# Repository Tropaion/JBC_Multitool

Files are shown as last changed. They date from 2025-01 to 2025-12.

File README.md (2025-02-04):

# JBC_Multitool
A slot extension device for JBC soldering stations with only one soldering iron terminal.
It is possible to connect:

* 2x soldering iron with the old hirose connector, like the [T210](https://www.weidinger.eu/de/wl13282) and [T245](https://www.weidinger.eu/de/wl13283)
* 2x soldering iron with the newer binder connector, like the [NT115A](https://www.weidinger.eu/de/wl44430) and [AN115A](https://www.weidinger.eu/de/wl45372)

THE PROJECT IS STILL WIP.

# Hardware
View the latest [PCB Interactive BOM](https://htmlpreview.github.io/?https://github.com/Tropaion/JBC_Multitool/blob/main/hardware/bom/ibom.html) or [KiCad Design](https://kicanvas.org/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).

<p float="left">
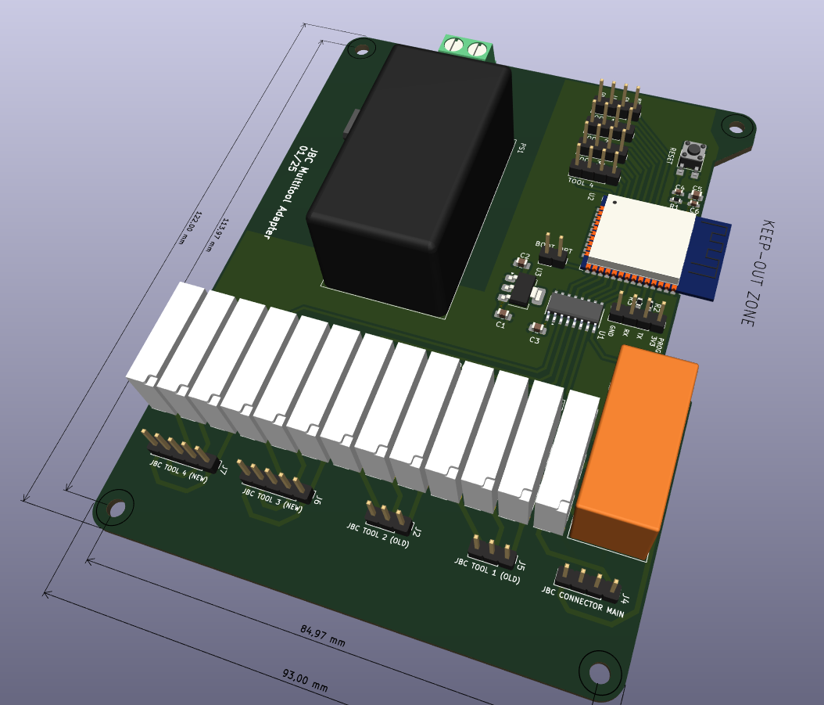
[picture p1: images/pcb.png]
  
</p>

# Attribution
This project is based on [this project from Lajt](https://lajtronix.eu/2024/02/08/jbc-3-tool-selector/)

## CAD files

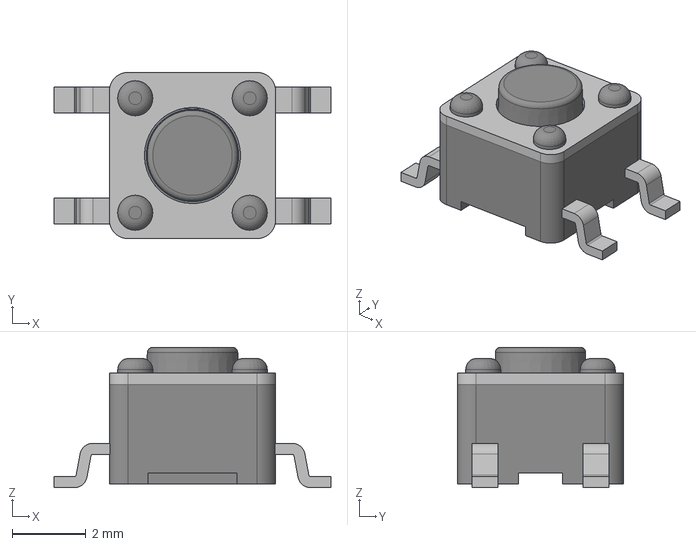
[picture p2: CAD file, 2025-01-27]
hardware/custom_components/3d/SW_SPST_TL3305A.step
7.50 x 4.50 x 3.80 mm

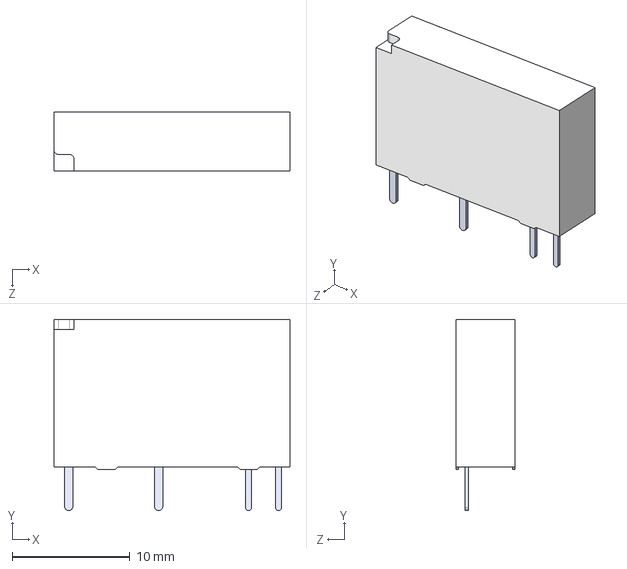
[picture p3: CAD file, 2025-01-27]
hardware/custom_components/3d/HF49FD.step
20.0 x 16.2 x 5.00 mm

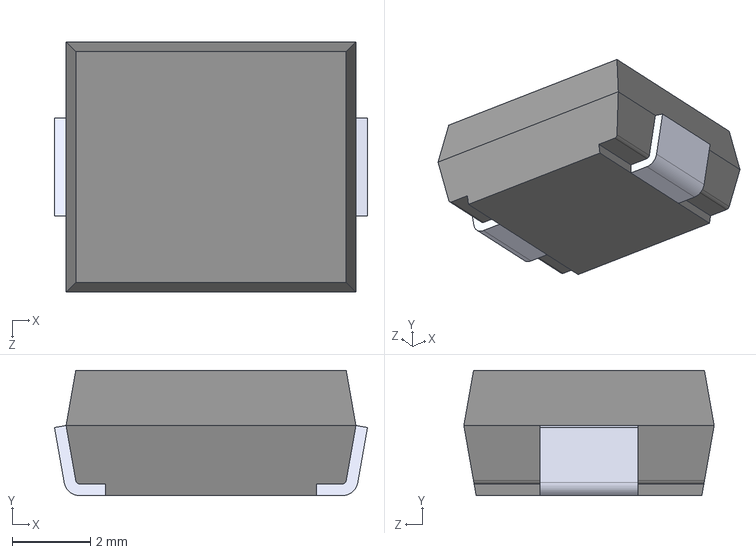
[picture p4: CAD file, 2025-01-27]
hardware/custom_components/3d/ERZ-VF2M470.step
8.00 x 3.20 x 6.40 mm

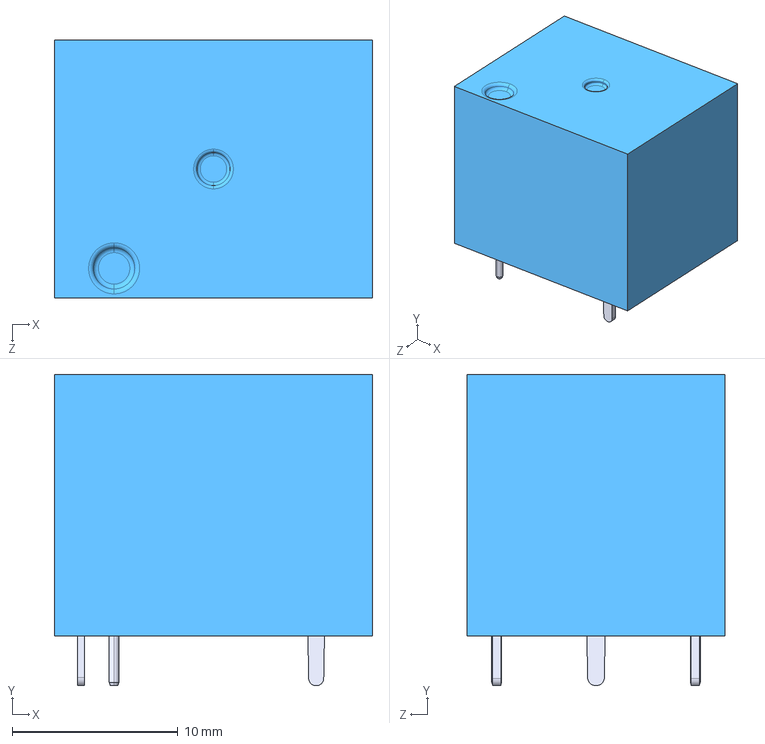
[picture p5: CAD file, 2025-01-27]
hardware/custom_components/3d/SRD-05VDC-SL-C.step
19.2 x 18.8 x 15.6 mm

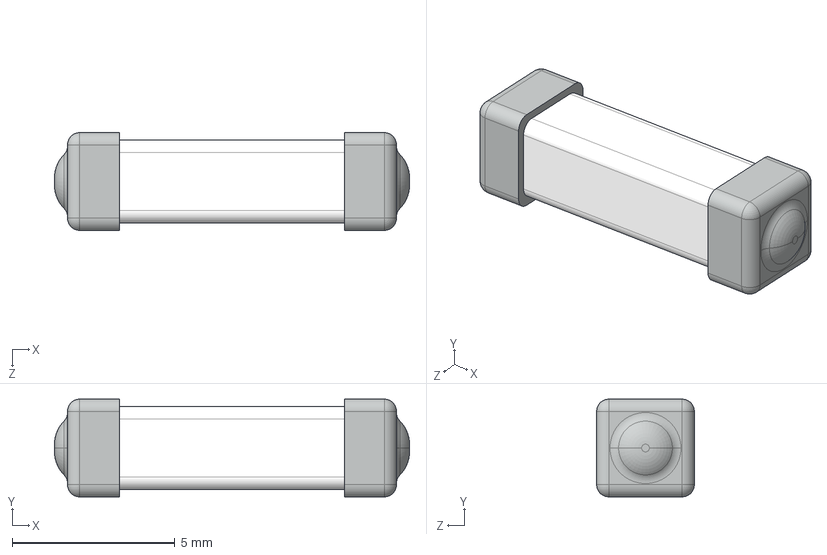
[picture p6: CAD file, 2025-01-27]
hardware/custom_components/3d/UMT250.step
10.9 x 3.00 x 3.00 mm

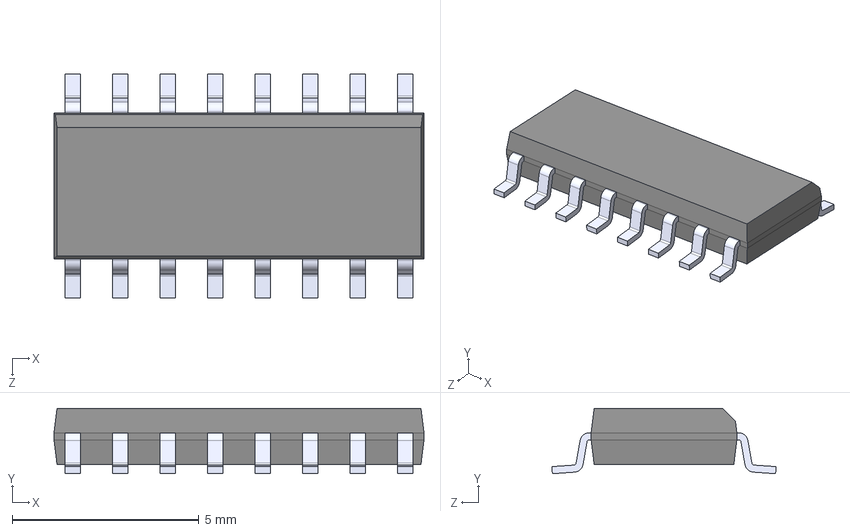
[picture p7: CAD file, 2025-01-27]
hardware/custom_components/3d/TPL7407LDR.step
9.90 x 1.75 x 6.00 mm

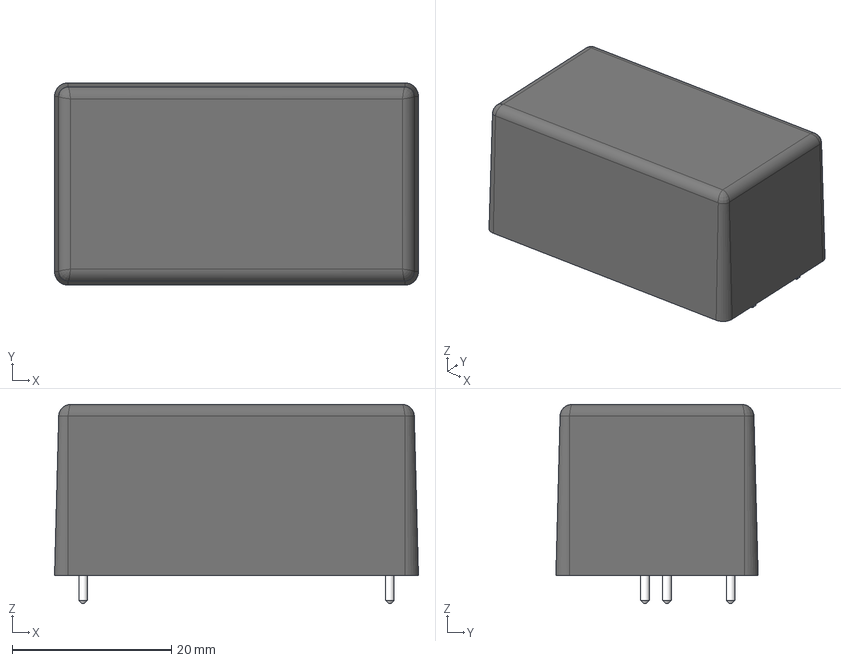
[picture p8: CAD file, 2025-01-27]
hardware/custom_components/3d/IRM-10 v3.step
45.7 x 25.4 x 25.0 mm

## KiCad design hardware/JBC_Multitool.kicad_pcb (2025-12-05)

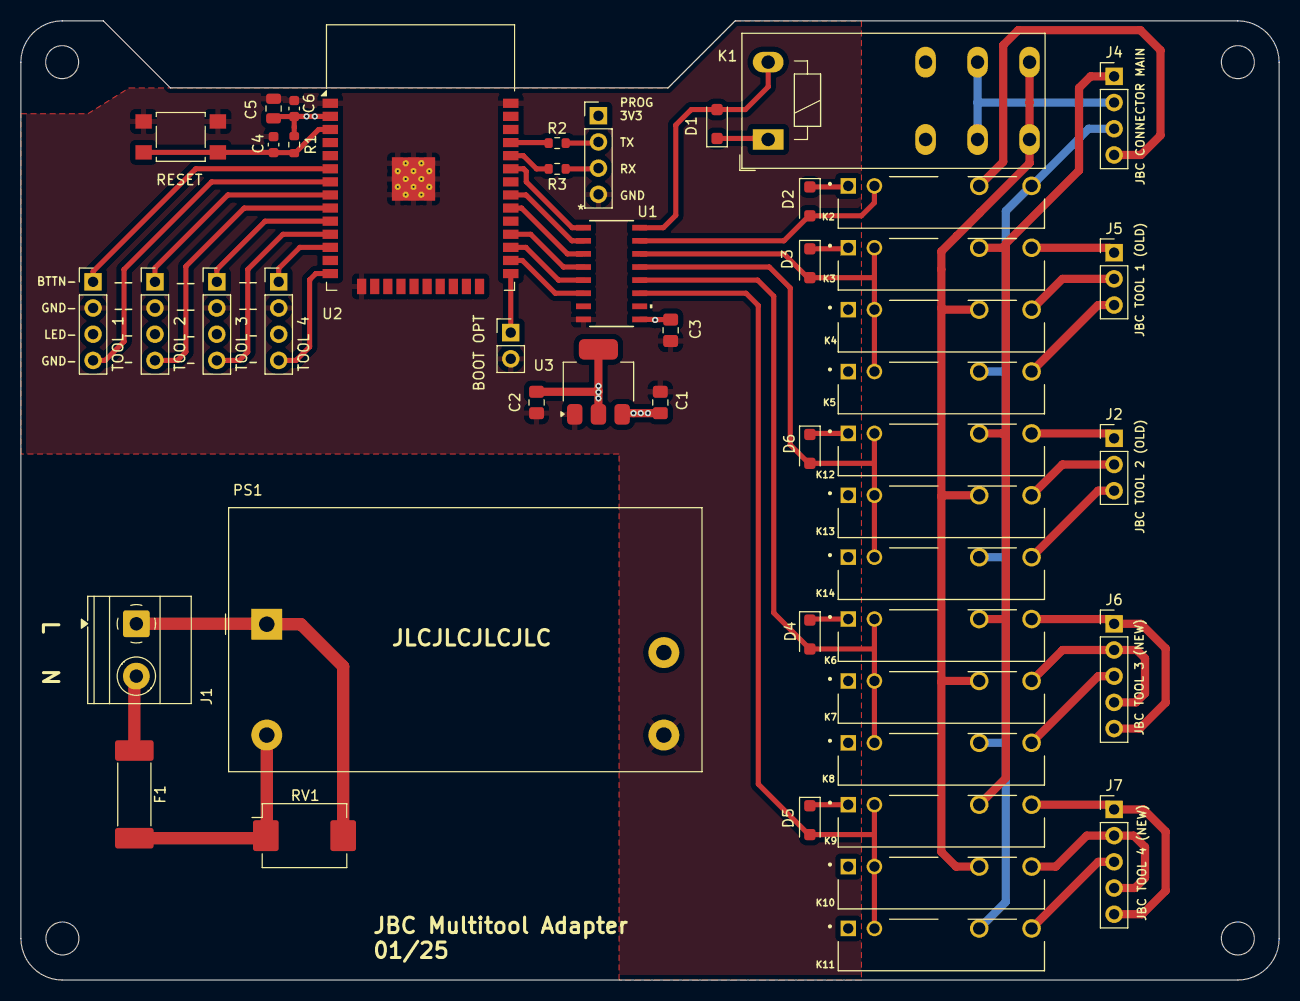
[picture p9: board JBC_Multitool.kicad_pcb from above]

Board: 2 copper layers, 122.0 x 93.0 mm, 52 parts (0 on the bottom side), 45 nets.

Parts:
BOOT_OPTION1: Conn_01x02; PinHeader_1x02_P2.54mm_Vertical
C1, C2: 1uF/10V; C_0805_2012Metric_Pad1.18x1.45mm_HandSolder
C3: 0.1uF; C_0805_2012Metric_Pad1.18x1.45mm_HandSolder
C4: 1µF/16V/10%; C_0603_1608Metric
C5: 22µF/10V; C_0805_2012Metric
C6: 0.1µF/50V/10%; C_0603_1608Metric
D1, D2, D3, D4, D5, D6: D; D_SOD-123F
ESP_RESET1: SW_Push; SW_SPST_TL3305A
F1: 100mA T; Fuse_Schurter_UMT250
H1, H2, H3, H4: MountingHole; MountingHole_3.2mm_M3
J1: Screw_Terminal_01x02; TerminalBlock_Phoenix_MKDS-1,5-2-5.08_1x02_P5.08mm_Horizont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
J2, J5: Mini XLR6; PinHeader_1x03_P2.54mm_Vertical
J4: Mini XLR6; PinHeader_1x04_P2.54mm_Vertical
J6, J7: Binder 09-0998-00-05; PinHeader_1x05_P2.54mm_Vertical
K1: RT314005; Relay_DPDT_Schrack-RT2-FormC_RM5mm
K2, K3, K4, K5, K6, K7, K8, K9, K10, K11, K12, K13, K14: HF49FD_005-1H12T; HF49FD
PROG1: Conn_01x04; PinHeader_1x04_P2.54mm_Vertical
PS1: IRM-10-5; Converter_ACDC_MeanWell_IRM-10-xx_THT
R1: 10kΩ 1%; R_0603_1608Metric
R2, R3: 160Ω; R_0603_1608Metric
RV1: Varistor 230V; Varistor_Panasonic_VF
SELECT_TOOL_1, SELECT_TOOL_2, SELECT_TOOL_3, SELECT_TOOL_4: Conn_01x04; PinHeader_1x04_P2.54mm_Vertical
U1: TPL7407LDR; D16_TEX
U2: ESP32-WROOM-32
U3: TLV1117-33; SOT-223-3_TabPin2

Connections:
+3.3V: C2.1, C5.2, C6.2, PROG1.1, R1.2, SELECT_TOOL_1.3, SELECT_TOOL_2.3, SELECT_TOOL_3.3, SELECT_TOOL_4.3, U2.2 (VDD), U3.2 (VO)
+5V: C1.1, C3.1, D1.1 (K), D2.1 (K), D3.1 (K), D4.1 (K), D5.1 (K), D6.1 (K), K1.A1, K2.1, K3.1, K4.1, K5.1, K6.1, K7.1, K8.1, K9.1, K10.1, K11.1, K12.1, K13.1, K14.1, PS1.4 (+Vo), U1.9 (COM), U3.3 (VI)
/ESP_RESET: C4.2, ESP_RESET1.2, R1.1, U2.3 (EN)
/GPIO0_BOOT_OPTION: BOOT_OPTION1.1, U2.25 (IO0)
/RELAIS_CARD/TOOL_1_SEL: D3.2 (A), K3.2, K4.2, K5.2, U1.14 (OUT3)
/RELAIS_CARD/TOOL_2_SEL: D6.2 (A), K12.2, K13.2, K14.2, U1.13 (OUT4)
/RELAIS_CARD/TOOL_3_SEL: D4.2 (A), K6.2, K7.2, K8.2, U1.12 (OUT5)
/RELAIS_CARD/TOOL_4_SEL: D5.2 (A), K9.2, K10.2, K11.2, U1.11 (OUT6)
/RELAIS_CARD/TOOL_CODE: K2.4, K5.3, K8.3, K11.3, K14.3
/RELAIS_CARD/TOOL_CODE_SEL: D2.2 (A), K2.2, U1.15 (OUT2)
/RELAIS_CARD/TOOL_POWER: K4.3, K7.3, K10.3, K13.3
/RELAIS_CARD/TOOL_POWER_SEL: D1.2 (A), K1.A2, U1.16 (OUT1)
/RELAIS_CARD/TOOL_SENSOR: J4.1, K3.3, K6.3, K9.3, K12.3
/SELECT_TOOL_1: SELECT_TOOL_1.1, U2.6 (IO34)
/SELECT_TOOL_2: SELECT_TOOL_2.1, U2.8 (IO32)
/SELECT_TOOL_3: SELECT_TOOL_3.1, U2.10 (IO25)
/SELECT_TOOL_4: SELECT_TOOL_4.1, U2.12 (IO27)
/SELECT_TOOL_LED_1: SELECT_TOOL_1.4, U2.7 (IO35)
/SELECT_TOOL_LED_2: SELECT_TOOL_2.4, U2.9 (IO33)
/SELECT_TOOL_LED_3: SELECT_TOOL_3.4, U2.11 (IO26)
/SELECT_TOOL_LED_4: SELECT_TOOL_4.4, U2.14 (IO12)
/TOOL_1_CTRL: U1.3 (IN3), U2.30 (IO18)
/TOOL_2_CTRL: U1.4 (IN4), U2.28 (IO17)
/TOOL_3_CTRL: U1.5 (IN5), U2.27 (IO16)
/TOOL_4_CTRL: U1.6 (IN6), U2.26 (IO4)
/TOOL_POWER_CTRL: U1.1 (IN1), U2.33 (IO21)
/TOOL_SENSOR_CTRL: U1.2 (IN2), U2.31 (IO19)
/UART0_PROG_RX: R3.2, U2.34 (RXD0/IO3)
/UART0_PROG_TX: R2.1, U2.35 (TXD0/IO1)
GND: BOOT_OPTION1.2, C1.2, C2.2, C3.2, C4.1, C5.1, C6.1, ESP_RESET1.1, PROG1.4, PS1.3 (-Vo), SELECT_TOOL_1.2, SELECT_TOOL_2.2, SELECT_TOOL_3.2, SELECT_TOOL_4.2, U1.8 (GND), U2.1 (GND), U2.15 (GND), U2.38 (GND), U2.39 (GND), U3.1 (GND)
unnamed: J1.1, PS1.1 (AC/N), RV1.2
unnamed: F1.1, J1.2
unnamed: J2.1, K12.4
unnamed: J2.2, K13.4
unnamed: J5.1, K3.4
unnamed: J5.2, K4.4
unnamed: J6.1, J6.5, K6.4
unnamed: J6.2, J6.4 (P3), K7.4
unnamed: J6.3, K8.4
unnamed: J7.1, J7.5, K9.4
unnamed: J7.2, J7.4 (P3), K10.4
unnamed: J7.3, K11.4
unnamed: PROG1.2, R2.2
unnamed: PROG1.3, R3.1
unnamed: F1.2, PS1.2 (AC/L), RV1.1

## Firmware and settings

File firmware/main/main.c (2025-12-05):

#include <stdio.h>
#include "driver\gpio.h"
#include "freeRTOS\freeRTOS.h"
#include "freeRTOS\task.h"

// Define ms delay
#define DELAY(ms)           vTaskDelay(pdMS_TO_TICKS(ms))
#define DEBOUNCE            DELAY(250)

// === RELAIS PINS ===
#define POWER_RELAIS        GPIO_NUM_21
#define SENSOR_RELAIS       GPIO_NUM_19
#define TOOL1_RELAIS        GPIO_NUM_18
#define TOOL2_RELAIS        GPIO_NUM_17
#define TOOL3_RELAIS        GPIO_NUM_16
#define TOOL4_RELAIS        GPIO_NUM_4

#define RELAIS_ENABLED      1
#define RELAIS_DISABLED     0

// === LED PINS ===
#define TOOL1_LED           GPIO_NUM_35
#define TOOL2_LED           GPIO_NUM_33
#define TOOL3_LED           GPIO_NUM_26
#define TOOL4_LED           GPIO_NUM_12

#define LED_ENABLED         0
#define LED_DISABLED        1

// === SWITCH PINS ===
#define TOOL1_SWITCH        GPIO_NUM_34
#define TOOL2_SWITCH        GPIO_NUM_32
#define TOOL3_SWITCH        GPIO_NUM_25
#define TOOL4_SWITCH        GPIO_NUM_27

#define SWITCH_ENABLED     0

// Variable which saves active tool
int active_tool = 0;

// Configures input and output pins
void configure_gpio() {
    // Configure output pins
    gpio_config_t output_conf = {};
    output_conf.mode = GPIO_MODE_OUTPUT;
    output_conf.pin_bit_mask = (1ULL << POWER_RELAIS) |
                           (1ULL << SENSOR_RELAIS) |
                           (1ULL << TOOL1_RELAIS) |
                           (1ULL << TOOL2_RELAIS) |
                           (1ULL << TOOL3_RELAIS) |
                           (1ULL << TOOL4_RELAIS) |
                           (1ULL << TOOL1_LED) |
                           (1ULL << TOOL2_LED) |
                           (1ULL << TOOL3_LED) |
                           (1ULL << TOOL4_LED);
    output_conf.pull_up_en = GPIO_PULLUP_DISABLE;
    output_conf.pull_down_en = GPIO_PULLDOWN_ENABLE;
    output_conf.intr_type = GPIO_INTR_DISABLE;
    ESP_ERROR_CHECK(gpio_config(&output_conf));

    // Configure input pins
    gpio_config_t input_conf = {};
    input_conf.mode = GPIO_MODE_INPUT;
    input_conf.pin_bit_mask = (1ULL << TOOL1_SWITCH) | 
                           (1ULL << TOOL2_SWITCH) | 
                           (1ULL << TOOL3_SWITCH) | 
                           (1ULL << TOOL4_SWITCH);
    input_conf.pull_up_en = GPIO_PULLUP_ENABLE;
    input_conf.pull_down_en = GPIO_PULLDOWN_DISABLE;
    input_conf.intr_type = GPIO_INTR_DISABLE;
    ESP_ERROR_CHECK(gpio_config(&input_conf));
}

// Sets everything to disabled
void disable_all() {
    // Disable all relais
    gpio_set_level(POWER_RELAIS, RELAIS_DISABLED);
    gpio_set_level(SENSOR_RELAIS, RELAIS_DISABLED);
    gpio_set_level(TOOL1_RELAIS, RELAIS_DISABLED);
    gpio_set_level(TOOL2_RELAIS, RELAIS_DISABLED);
    gpio_set_level(TOOL3_RELAIS, RELAIS_DISABLED);
    gpio_set_level(TOOL4_RELAIS, RELAIS_DISABLED);

    // Disable all leds
    gpio_set_level(TOOL1_LED, LED_DISABLED);
    gpio_set_level(TOOL2_LED, LED_DISABLED);
    gpio_set_level(TOOL3_LED, LED_DISABLED);
    gpio_set_level(TOOL4_LED, LED_DISABLED);
}

// Enables tool 1 (t210)
void set_tool_1() {
    // Check if tool is aready active
    if (active_tool == 1) {
        // Debounce
        DELAY(200);
        return;
    }

    // Disable everything
    disable_all();

    // Enable required relais
    // T210, small soldering pen
    gpio_set_level(SENSOR_RELAIS, RELAIS_ENABLED);
    gpio_set_level(TOOL1_RELAIS, RELAIS_ENABLED);

    // Wait for JBC
    DELAY(300);

    // Enable power
    gpio_set_level(POWER_RELAIS, RELAIS_ENABLED);
  
    // Enable led
    gpio_set_level(TOOL1_LED, LED_ENABLED);
  
    // Set active tool
    active_tool = 1;
}

// Enables tool 2
void set_tool_2() {
    // Check if tool is aready active
    if (active_tool == 2) {
        // Debounce
        DELAY(200);
        return;
    }
  
    // Disable everything
    disable_all();
  
    // Enable required relais
    gpio_set_level(TOOL2_RELAIS, RELAIS_ENABLED);
  
    // Wait for JBC
    DELAY(300);
  
    // Enable power
    gpio_set_level(POWER_RELAIS, RELAIS_ENABLED);
  
    // Enable led
    gpio_set_level(TOOL2_LED, LED_ENABLED);
  
    // Set active tool
    active_tool = 2;
}

// Enables tool 3
void set_tool_3() {
    // Check if tool is aready active
    if (active_tool == 3) {
        // Debounce
        DELAY(200);
        return;
    }
  
    // Disable everything
    disable_all();
  
    // Enable required relais
    gpio_set_level(TOOL3_RELAIS, RELAIS_ENABLED);
  
    // Wait for JBC
    DELAY(300);
  
    // Enable power
    gpio_set_level(POWER_RELAIS, RELAIS_ENABLED);
  
    // Enable led
    gpio_set_level(TOOL3_LED, LED_ENABLED);
  
    // Set active tool
    active_tool = 3;
}

// Enables tool 4
void set_tool_4() {
    // Check if tool is aready active
    if (active_tool == 4) {
        // Debounce
        DELAY(200);
        return;
    }
  
    // Disable everything
    disable_all();
  
    // Enable required relais
    gpio_set_level(TOOL4_RELAIS, RELAIS_ENABLED);
  
    // Wait for JBC
    DELAY(300);
  
    // Enable power
    gpio_set_level(POWER_RELAIS, RELAIS_ENABLED);
  
    // Enable led
    gpio_set_level(TOOL4_LED, LED_ENABLED);
  
    // Set active tool
    active_tool = 4;
}

void app_main(void)
{
    // Configure digital I/O PINs
    configure_gpio();

    // Disable periphery
    disable_all();

    while(1)
    {
        // Check if button was pressed
        if (gpio_get_level(TOOL1_SWITCH) == SWITCH_ENABLED) {
            // Enable tool 1
            set_tool_1();

            // Wait debounce time
            DEBOUNCE;

            // Wait for button to be released
            while(gpio_get_level(TOOL1_SWITCH) == SWITCH_ENABLED) {
                // Wait debounce time
                DEBOUNCE;
            }
        }

        // Check if button was pressed
        if (gpio_get_level(TOOL2_SWITCH) == SWITCH_ENABLED) {
            // Enable tool 2
            set_tool_2();

            // Wait debounce time
            DEBOUNCE;

            // Wait for button to be released
            while(gpio_get_level(TOOL2_SWITCH) == SWITCH_ENABLED) {
                // Wait debounce time
                DEBOUNCE;
            }
        }

        // Check if button was pressed
        if (gpio_get_level(TOOL3_SWITCH) == SWITCH_ENABLED) {
            // Enable tool 3
            set_tool_3();

            // Wait debounce time
            DEBOUNCE;

            // Wait for button to be released
            while(gpio_get_level(TOOL3_SWITCH) == SWITCH_ENABLED) {
                // Wait debounce time
                DEBOUNCE;
            }
        }

        // Check if button was pressed
        if (gpio_get_level(TOOL4_SWITCH) == SWITCH_ENABLED) {
            // Enable tool 4
            set_tool_4();

            // Wait for button to be released
            while(gpio_get_level(TOOL4_SWITCH) == SWITCH_ENABLED) {
                // Wait debounce time
                DEBOUNCE;
            }
        }
        // Let IDLE0 task reset watchdog
        vTaskDelay(1);
    }
}

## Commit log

2025-01-27 kicad files
    [ERZ-VF2M470.step, HF49FD.step, IRM-10 v3.step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]
2025-01-28 corrected pin numbers on terminal footprint, changed switch-LED configuration
    [JBC_Multitool.kicad_pcb, JBC_Multitool.kicad_sch, relais.kicad_sch]
2025-02-01 added 2.nd "old" jbc connector
    [JBC_Multitool.kicad_pcb, JBC_Multitool.kicad_sch, relais.kicad_sch]
2025-02-02 changed pcb front silkscreen
    [JBC_Multitool.kicad_pcb]
2025-02-02 added tool change switch 4
    [JBC_Multitool.kicad_pcb, JBC_Multitool.kicad_sch]
2025-02-04 add gerber and bom
    [JBC_Multitool.kicad_pcb, JBC_Multitool.kicad_sch, relais.kicad_sch]
2025-02-04 update bom
2025-02-27 fix pcb
    [JBC_Multitool.kicad_pcb, JBC_Multitool.kicad_sch, relais.kicad_sch]
2025-12-04 Add files via upload
    PCB und Schaltplan überarbeitet.
    GPIO5 & GPIO14 jetzt „not connected“, da diese GPIOs beim Boot auf HIGH gesetzt werden und die Relais und die LED anschalteten.
    [JBC_Multitool.kicad_pcb, JBC_Multitool.kicad_sch]
2025-12-04 Add files via upload
    main.c angepasst an geänderte/n PCB & Schaltplan.
    GPIO5 & GPIO14 werden nun nicht mehr verwendet.
2025-12-05 new bom and gerber
    [JBC_Multitool.kicad_pcb]
